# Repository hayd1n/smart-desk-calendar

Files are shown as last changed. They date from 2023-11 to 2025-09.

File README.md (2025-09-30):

# Smart Desk Calendar

ESP32 + E-Paper + Rust

3D Rendering

Modeling

3D Printed

Assemblyed

UI Design 1

UI Design 2

Prototype

Programming

Exhibition

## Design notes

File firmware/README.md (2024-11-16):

# Firmware

## MCU

- ESP32

## Wire Connection

| ESP32 | E-Paper |
| --- | --- |
| GPIO 13 | CLK |
| GPIO 14 | DIN |
| GPIO 25 | BUSY |
| GPIO 26 | RST |
| GPIO 15 | CS |
| GPIO 27 | DC |
| GPIO 23 | PWR |

## Design

### Mode

| Mode | Description |
| --- | --- |
| Initialize | Guides the user through the initial setup. |
| Settings | The device stays connected to the Internet and users can connect to the device for setup. |
| Normal | The regular state of the device, refreshing the information on the screen at regular intervals. Most of the time it is hibernating. |
| Low Power  | The device no longer refreshes information and displays a low-battery alert on the screen. |

### Function Key

The key on the back is used as a function key.

#### Initialize Mode

None

#### Settings Mode

| Operation | Behavior | Alert |
| --- | --- | ----- |
| Press | Leave settings mode | |

#### Normal Mode

| Operation | Behavior | Alert |
| --- | --- | --- |
| Press | Refresh home page | |
| Press & hold 3 secs | Enter settings mode | |
| Press & hold 7 secs | Reset device | LED blinking |

#### Low Power Mode

| Operation | Behavior | Alert |
| --- | --- | ----- |
| Press | Re-check the device's power level and return to normal mode when the power level is sufficient | |

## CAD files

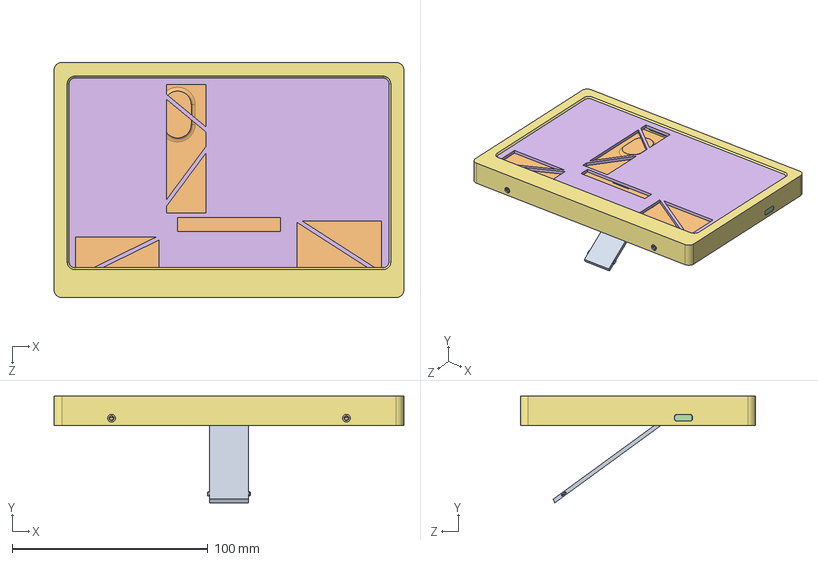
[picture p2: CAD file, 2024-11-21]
3D Models/smart desk calendar.SLDASM
178.8 x 54.5 x 120.2 mm
Case
Circuit Mount Case
PCB
ESP32
User Library-DTSM-2 x 2
Back cover
Stand

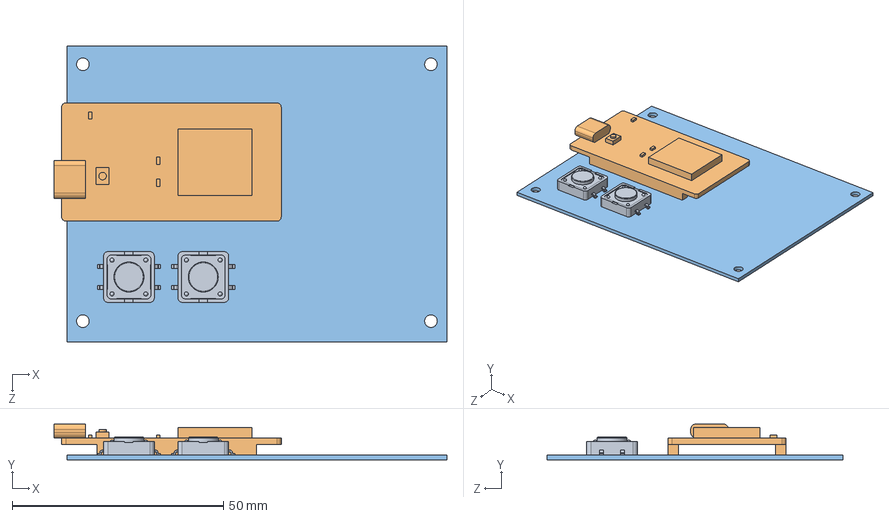
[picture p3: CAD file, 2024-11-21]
3D Models/Modules/Circuit Board.SLDASM
93.0 x 8.52 x 70.0 mm
PCB
ESP32
User Library-DTSM-2 x 2

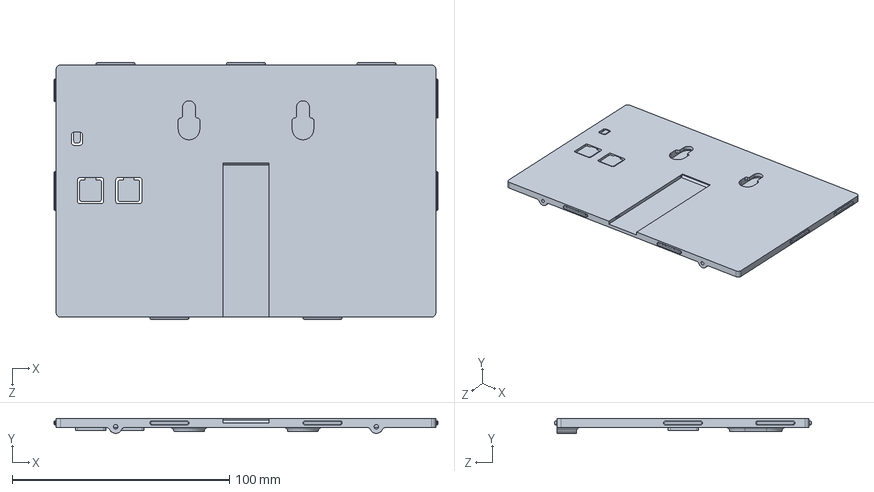
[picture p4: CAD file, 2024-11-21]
3D Models/Case/Back cover.SLDPRT
176.7 x 6.78 x 118.1 mm

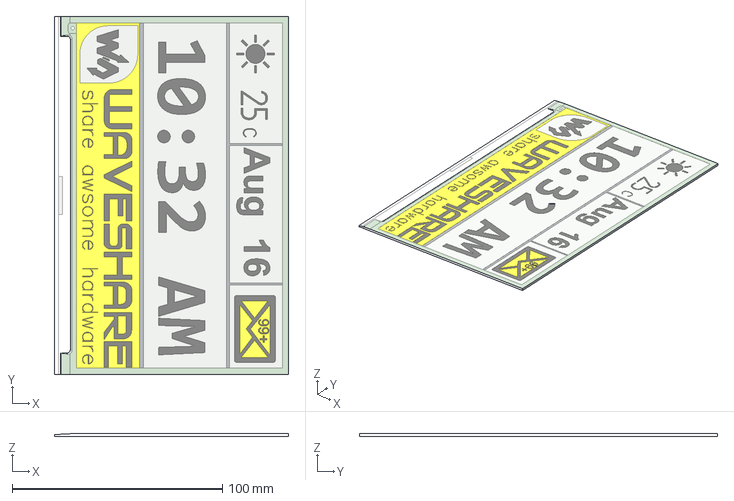
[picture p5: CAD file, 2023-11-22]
3D Models/Modules/7-5in-e-ink-display-assortment-1.snapshot.5/Waveshare 7.5 E-ink (C) - No Cable.stp
111.4 x 170.4 x 1.19 mm

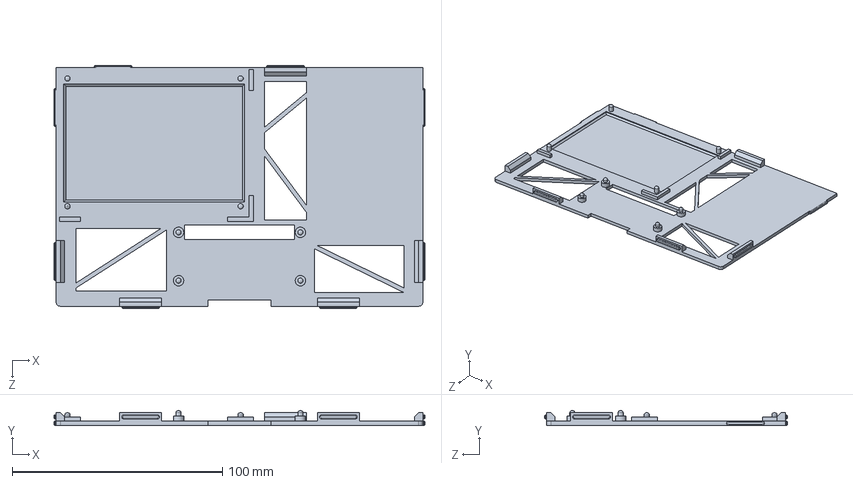
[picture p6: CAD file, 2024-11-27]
3D Models/Modules/Circuit Mount Case.SLDPRT
176.6 x 7.00 x 115.5 mm

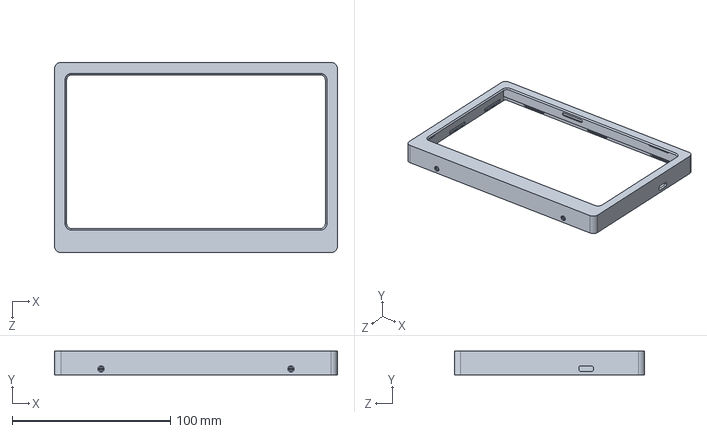
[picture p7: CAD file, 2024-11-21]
3D Models/Case/Case.SLDPRT
178.8 x 15.0 x 120.2 mm

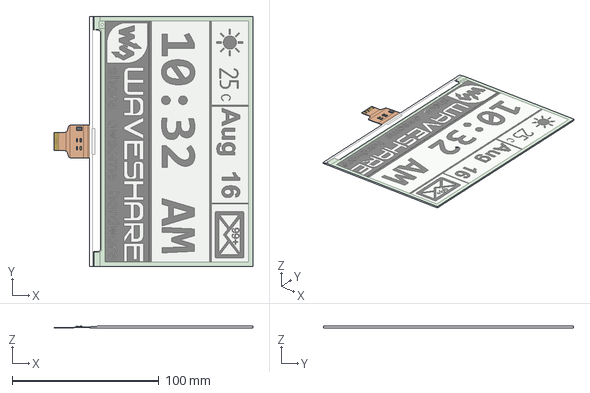
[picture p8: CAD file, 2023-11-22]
3D Models/Modules/7-5in-e-ink-display-assortment-1.snapshot.5/Waveshare 7.5 E-ink - Display Flat Mount.stp
135.5 x 170.4 x 1.26 mm

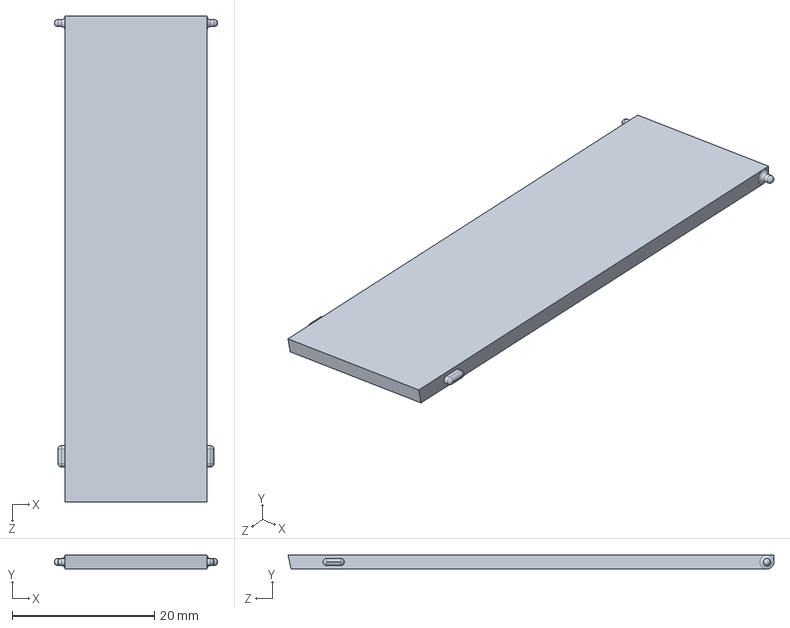
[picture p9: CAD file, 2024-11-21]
3D Models/Case/Stand.SLDPRT
23.0 x 2.00 x 68.4 mm

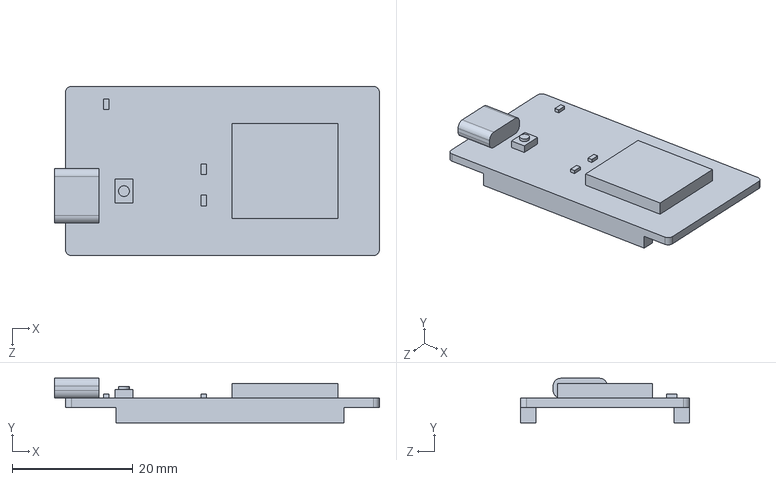
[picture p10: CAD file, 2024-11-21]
3D Models/Modules/ESP32.SLDPRT
53.8 x 7.37 x 28.0 mm

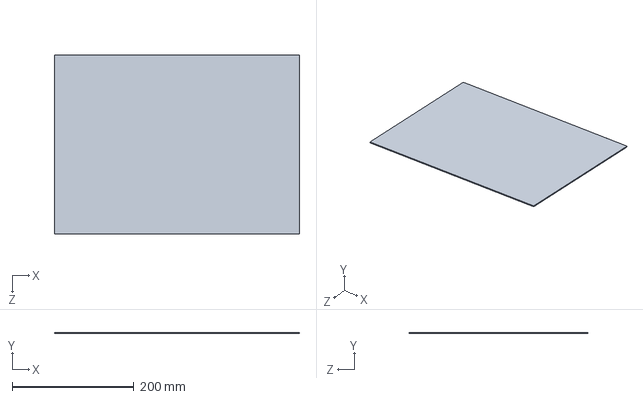
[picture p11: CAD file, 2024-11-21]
3D Models/Modules/Floor.SLDPRT
401.8 x 2.00 x 293.2 mm

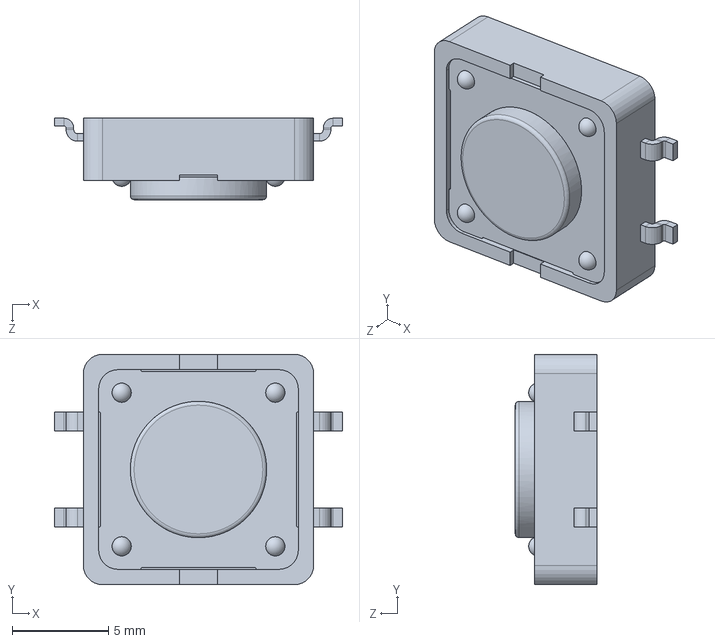
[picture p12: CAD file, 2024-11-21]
3D Models/Modules/User Library-DTSM-2.sldprt
15.0 x 12.0 x 4.25 mm

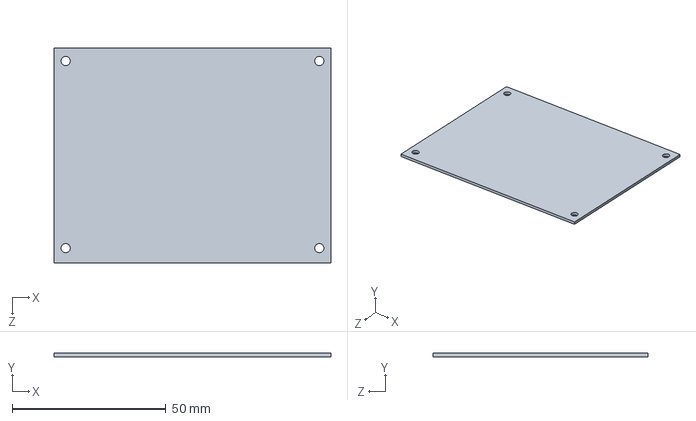
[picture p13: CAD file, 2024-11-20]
3D Models/Modules/PCB.SLDPRT
90.0 x 1.15 x 70.0 mm

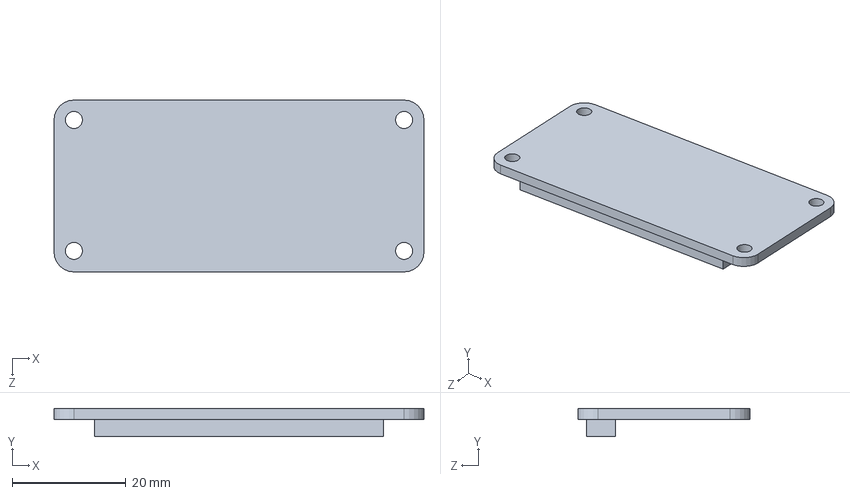
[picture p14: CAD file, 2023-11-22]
3D Models/Modules/E-Paper Driver HAT.SLDPRT
65.0 x 5.00 x 30.2 mm

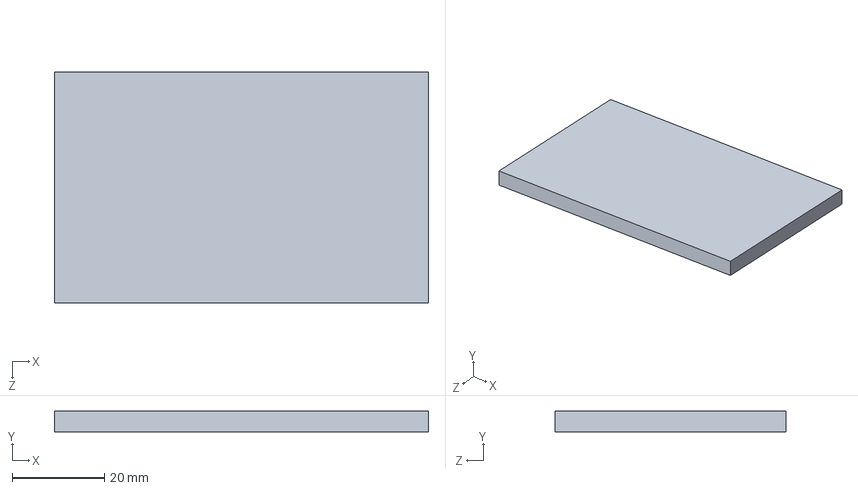
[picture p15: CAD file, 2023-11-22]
3D Models/Modules/Battery LiIon 3000mAh.SLDPRT
81.0 x 4.50 x 50.0 mm

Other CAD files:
3D Models/Modules/7-5in-e-ink-display-assortment-1.snapshot.5/Waveshare 7.5 E-ink (C) - Display Flat Mount.stp
3D Models/Modules/7-5in-e-ink-display-assortment-1.snapshot.5/Waveshare 7.5 E-ink - No Cable.stp
3D Models/Modules/7-5in-e-ink-display-assortment-1.snapshot.5/Waveshare 7.5 E-ink (B) - Display Flat Mount.stp
3D Models/Modules/7-5in-e-ink-display-assortment-1.snapshot.5/Waveshare 7.5 E-ink (B) - No Cable.stp
3D Models/Modules/E-Paper 7in5.SLDPRT

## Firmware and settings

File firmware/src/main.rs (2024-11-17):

#![feature(duration_constructors)]

use app::App;
use board::Board;
use esp_idf_svc::{
    eventloop::EspSystemEventLoop, hal::prelude::Peripherals, nvs::EspDefaultNvsPartition,
};

pub mod app;
pub mod board;
pub mod calendar;
pub mod common;
pub mod display;
pub mod http;

fn main() {
    // It is necessary to call this function once. Otherwise some patches to the runtime
    // implemented by esp-idf-sys might not link properly. See https://github.com/esp-rs/esp-idf-template/issues/71
    esp_idf_svc::sys::link_patches();

    // Bind the log crate to the ESP Logging facilities
    esp_idf_svc::log::EspLogger::initialize_default();

    let peripherals = Peripherals::take().unwrap();
    let sysloop = EspSystemEventLoop::take().unwrap();
    let nvs = EspDefaultNvsPartition::take().unwrap();

    let board = Board::init(peripherals, sysloop.clone(), nvs.clone());

    let app = App::new(board, sysloop, nvs);
    app.run();
}

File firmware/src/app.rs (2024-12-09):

#![allow(dead_code)]

use std::{
    convert::Infallible,
    error::Error,
    fmt::{self, Debug},
    str::{from_utf8, Utf8Error},
    sync::mpsc::{self, RecvTimeoutError},
    time::Duration,
};

use chrono::{Datelike, NaiveTime};
use chrono_tz::Tz;
use const_random::const_random;
use embedded_graphics::{
    mono_font::{ascii::FONT_10X20, MonoTextStyle},
    prelude::Point,
    text::Text,
    Drawable,
};
use embedded_svc::http::client::Client;
use epd_waveshare::{color::Color, graphics::VarDisplay, prelude::WaveshareDisplay};
use esp_idf_svc::{
    eventloop::EspSystemEventLoop,
    hal::{reset, spi::SpiError},
    http::{
        client::EspHttpConnection,
        server::{Configuration as HttpServerConfig, EspHttpServer},
        Method,
    },
    io::{EspIOError, Write},
    nvs::{EspDefaultNvsPartition, EspNvs, NvsDefault},
    sntp::{EspSntp, SyncStatus},
    sys::EspError,
    wifi,
};
use gui::{
    draw::DrawError,
    font,
    page::main_page::{Event, MainPage},
    text::Text as GuiText,
};
use serde::{Deserialize, Serialize};
use u8g2_fonts::{
    types::{HorizontalAlignment, VerticalPosition},
    FontRenderer,
};

use crate::{
    board::Board,
    calendar::IcsDownloader,
    common::{get_time, NVS_NAMESPACE},
    display::{create_display, Black},
    http::create_https_client,
};

#[derive(Debug)]
pub enum Mode {
    Initialize,
    Setting,
    Normal,
    LowPower,
}

#[derive(Debug, Clone, Serialize, Deserialize)]
#[serde(rename_all = "camelCase")]
pub struct WifiConfig {
    pub ssid: heapless::String<32>,
    pub password: heapless::String<64>,
    pub auth_method: wifi::AuthMethod,
}

impl WifiConfig {
    pub fn to_client_config(&self) -> wifi::ClientConfiguration {
        wifi::ClientConfiguration {
            ssid: self.ssid.clone(),
            password: self.password.clone(),
            auth_method: self.auth_method,
            scan_method: wifi::ScanMethod::FastScan,
            ..Default::default()
        }
    }
}

#[derive(Debug, Clone)]
pub struct AppConfig {
    pub device_id: u8,
}

#[derive(Debug, Clone, Serialize, Deserialize)]
#[serde(rename_all = "camelCase")]
pub struct AppSettings {
    // Wi-Fi
    pub wifi_config: WifiConfig,
    // Timezone
    pub timezone: Tz,
    // Misc
    pub refresh_interval: Duration,
    // Calendar
    pub calendar_url: Vec<String>, // Calendar URL max 8
}

impl Default for AppSettings {
    fn default() -> Self {
        let calendar_url = env!("ICS_URL")
            .split(";")
            .map(|s| String::from(s))
            .collect();

        AppSettings {
            wifi_config: WifiConfig {
                ssid: env!("WIFI_SSID").try_into().unwrap(),
                password: env!("WIFI_PASSWORD").try_into().unwrap(),
                auth_method: env!("WIFI_AUTH_MODE").try_into().unwrap(),
            },
            timezone: chrono_tz::Asia::Taipei,
            refresh_interval: Duration::from_mins(5),
            calendar_url,
        }
    }
}

pub trait AppMode {
    fn new(app: App) -> Self;
    fn run(&mut self);
    fn retrieve(self) -> App;
}

pub struct InitializeMode {
    app: App,
    wifi_ap_config: wifi::AccessPointConfiguration,
    wifi_client_config: wifi::ClientConfiguration,
}

impl InitializeMode {
    fn setup_wifi(&mut self) -> Result<(), AppError> {
        self.app
            .board
            .wifi
            .set_configuration(&wifi::Configuration::Mixed(
                self.wifi_client_config.clone(),
                self.wifi_ap_config.clone(),
            ))?;

        Ok(())
    }

    fn connect_wifi(&mut self) -> Result<(), AppError> {
        // Connect Wifi
        self.app.board.wifi.connect()?;
        // Wait until the network interface is up
        self.app.board.wifi.wait_netif_up().ok();
        Ok(())
    }

    fn initialize_wifi(&mut self) -> Result<(), AppError> {
        // Setup Wifi
        self.setup_wifi()?;
        // Start Wifi
        self.app.board.wifi.start()?;
        Ok(())
    }

    fn initialize(&mut self) -> Result<(), AppError> {
        log::info!("InitializeMode::initialize");
        self.initialize_wifi()?;

        Ok(())
    }

    fn run_internal(&mut self) -> Result<(), AppError> {
        // Initialize the app mode
        self.initialize()?;

        // Display the initializing screen
        let display = &mut self.app.display;
        let text_style = MonoTextStyle::new(&FONT_10X20, Black);
        Text::new("Initialize Mode", Point::new(30, 30), text_style).draw(display)?;
        Text::new(
            &format!(
                "WiFi SSID: {}, Password: {}",
                self.wifi_ap_config.ssid, self.wifi_ap_config.password
            ),
            Point::new(30, 50),
            text_style,
        )
        .draw(display)?;

        // Update and display the frame
        self.app.update_and_display()?;

        // TEST: Test HTTP Server
        // HTTP Configuration
        // Create HTTP Server Connection Handle
        let mut httpserver = EspHttpServer::new(&HttpServerConfig::default())?;

        // Define Server Request Handler Behaviour on Get for Root URL
        httpserver.fn_handler(
            "/",
            Method::Get,
            |request| -> core::result::Result<(), EspIOError> {
                let html = "Hello world!";
                let mut response = request.into_ok_response()?;
                response.write_all(html.as_bytes())?;
                Ok(())
            },
        )?;

        let (tx, rx) = mpsc::channel();

        httpserver.fn_handler(
            "/wifi",
            Method::Post,
            move |mut request| -> Result<(), AppError> {
                let mut buffer = [0_u8; 256];
                let bytes_read = request.read(&mut buffer)?;
                let recv_str = from_utf8(&buffer[0..bytes_read])?;
                let wifi_config_json: WifiConfig = serde_json::from_str(recv_str)?;

                // Send the wifi configuration to the main thread
                tx.send(wifi_config_json).unwrap();

                let html = format!("Received: {}", recv_str);
                let mut response = request.into_ok_response()?;
                response.write_all(html.as_bytes())?;
                Ok(())
            },
        )?;

        log::info!("Initialize mode started");

        loop {
            match rx.recv_timeout(Duration::from_secs(1)) {
                Ok(wifi_config_json) => {
                    log::info!("Received wifi config: {:?}", wifi_config_json);
                    self.wifi_client_config = wifi_config_json.to_client_config();

                    // Re-setup the wifi
                    self.setup_wifi()?;

                    // Connect to the wifi
                    self.connect_wifi()?;

                    if self.app.board.wifi.is_connected()? {
                        log::info!("Connected to Wi-Fi");
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

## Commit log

2023-11-22 add 3D models
    [case.SLDPRT, epaper_7in5.SLDPRT, smart desk calendar.SLDASM]
2023-11-22 update case deisgns
    [Battery LiIon 3000mAh.SLDPRT, Case.SLDPRT, Circuit Board.SLDASM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]
2023-11-23 modify for e-paper wiring
    [Circuit Mount Case.SLDPRT]
2023-12-03 optimize case design
    [Case.SLDPRT, Circuit Board.SLDASM, Circuit Mount Case.SLDPRT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]
2024-11-08 feat(firmware): add LED signals to indicate power-on/off status
2024-11-11 fix(firmware): fix wrong function export
    [main.rs]
2024-11-20 feat(3d models): re-design case
    [Back cover.SLDPRT, Case.3MF, Case.SLDPRT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]
2024-11-21 feat(3d models): add back cover model
    [Back cover.SLDPRT, Case.3MF, Case.SLDPRT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]
2024-11-21 chore(3d models): delete mesh file
    [Case.3MF]
2024-11-27 fix(3d models): fix wrong groove position for e-paper driver board
    [Circuit Mount Case.SLDPRT]
